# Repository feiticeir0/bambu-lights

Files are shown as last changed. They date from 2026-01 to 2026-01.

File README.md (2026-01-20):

# Bambu P1S – External LED Light (MQTT Controlled)

This project adds an external LED light strip to the Bambu Lab P1S printer, synchronized with the internal chamber light using MQTT over the local network.

The goal is to improve visibility inside the printer while keeping the behavior fully aligned with the printer’s native light control, without modifying firmware or adding manual switches.

---

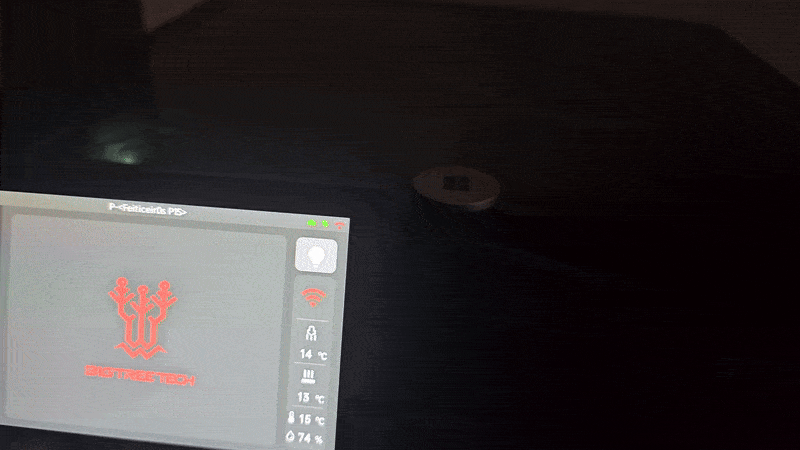
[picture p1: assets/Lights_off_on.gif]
Bambu Lights


## Introduction

The built-in light of the Bambu P1S is functional but relatively weak, especially for long prints, monitoring, or video recording.

You have two options to add a LED strip to the printer:

* Add a LED strip that consumes less than 0.3 amps and you can replace the connection to the onboard LED light and use the printer button to turn the light on and off
* Add a LED strip that consumes more than 0.3 amps, use an external power and not control the leds using the printer. 

Instead of using an always-on LED strip or a separate switch, and not being able to use the printer to turn the lights on and off, this project listens to the printer’s own MQTT messages and mirrors the state of the internal chamber light. 

When the chamber light turns on, the external LED strip turns on. When it turns off, the external light turns off as well, using smooth fade-in and fade-out transitions.

Everything runs locally.

## Why This Project

- Improve internal visibility of the printer
- Keep lighting behavior consistent with the printer
- No firmware modifications
- No cloud services
- No manual controls
- Fully reversible installation
- Smooth and non-intrusive light transitions

## How It Works

- An ESP32 connects to the same local network as the printer
- It subscribes to the MQTT topic published by the printer
- The printer reports its internal state, including the chamber light
- When the chamber light state changes:
  - ON → external LED fades in
  - OFF → external LED fades out
- A MOSFET switches the LED power safely

## Hardware Required

### Electronics
- ESP32 board (Seeed XIAO ESP32-S3 used in this project)
- IRLZ44N MOSFET
- 10k resistor
- 220 ohms resistor
- 5mm LED (color not important)
- 2x USB-A Pcb mount

### Power

- Powered via USB
- LED power is routed through the ESP32 5 V pin by design
- Common ground between ESP32 and LED strip

## 3D Printed Parts

A custom 3D printed enclosure is used to:

- Hold the PCB securely
- Protect the electronics
- Provide cable strain relief
- Mount the assembly on the back of the printer

[STL files are provided and can be printed without supports.](3D/README.md)

## Electrical Schematic and PCB

The schematic includes:

- ESP32 GPIO to MOSFET gate connection
- Gate pull-down resistor
- MOSFET low-side switching for the LED strip
- Shared ground reference
- Status LED output

The schematic files are included in the repository, in the [PCB directory.](Electrical/README.md)

### PCB
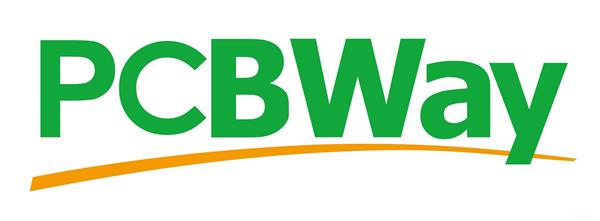
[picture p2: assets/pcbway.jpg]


A dedicated PCB was designed specifically for this project.

[You can get it directly from PCBWay.](https://www.pcbway.com/project/shareproject/Bambu_Lights_8b3fba62.html) 

**FYI:** I don't get anything from it, but they have sponsered it and I'm gratefull for it. 

The PCB is not necessary for the project - in [PCB](PCB/README.md) I have photos of the prototype and the schematics from Fritzing. 

## Code

The code runs on the Xiao ESP32-S3 and handles:

- WiFi connection (station mode)
- Secure MQTT connection to the printer (TLS)
- JSON parsing of printer status messages
- Detection of chamber light state changes
- PWM-based fade-in and fade-out animations
- Automatic reconnection to WiFi and MQTT

## Security

**TLS certificate validation is disabled, which is acceptable in a trusted local network environment.**

## Assembly
Here's pictures of everything assembled. [You can read more instructions on Electrical](Electrical/README.md)

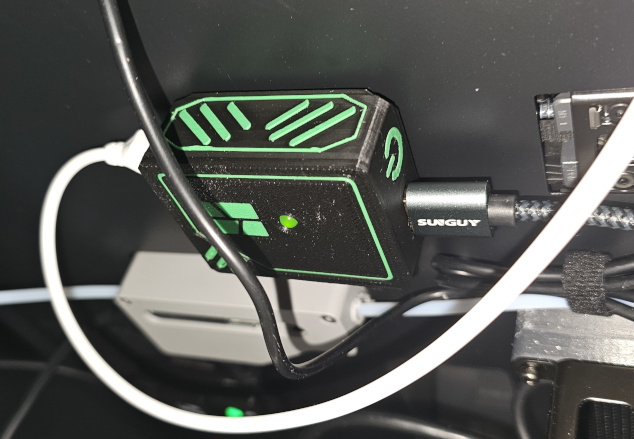
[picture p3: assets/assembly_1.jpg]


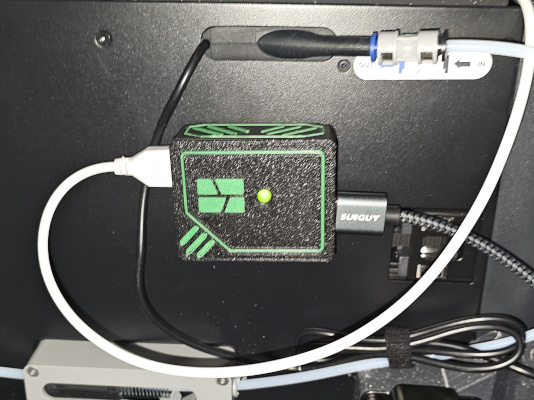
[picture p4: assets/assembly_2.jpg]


For power, I've connected it to [Biqu Panda Branch](https://biqu.equipment/products/biqu-power-supply-solutions?variant=42174177673314). 

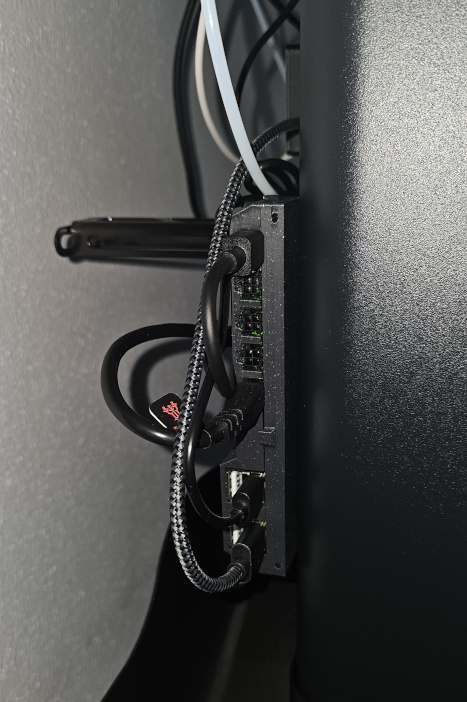
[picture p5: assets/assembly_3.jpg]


## TODO
- Verify if we are getting all the MQTT strings from the printer. Sometimes the lights don't turn on, because the string we're searching for does not appears. 

## License

This project is free software: you can redistribute it and/or modify
it under the terms of the GNU General Public License
as published by the Free Software Foundation, either version 3 of the License,
or (at your option) any later version.

This project is distributed in the hope that it will be useful,
but WITHOUT ANY WARRANTY; without even the implied warranty of
MERCHANTABILITY or FITNESS FOR A PARTICULAR PURPOSE. See the GNU General Public License for more details.

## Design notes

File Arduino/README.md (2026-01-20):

## Code

The code hasn't much in need of change, just some configurations.

First, you need to add your Wi-Fi details
```c
// WiFi
const char* WIFI_SSID     = "";    // Your wifi network
const char* WIFI_PASSWORD = "";    // your wifi network password
```

The next information needed is from your printer. 
* **PRINTER_IP** is the address of the printer on your network
* **ACCESS_CODE** you get it from the printer
* **PRINTER_SERIAL** is your printer serial number that you can also get from the menus of the printer. 

```c
// Bambu
const char* PRINTER_IP      = "xxx.xxx.xxx.xxx";  // Printer IP
const int   PRINTER_PORT    = 8883;    // No need to change - static
const char* PRINTER_USER    = "bblp";  // no change - static
const char* ACCESS_CODE     = "";      // LAN Access Code (From printer)
const char* PRINTER_SERIAL  = "";    // Serial number (From printer)
```

These are the libraries that you're going to need:
```c
#include <WiFi.h>
#include <WiFiClientSecure.h>
#include <PubSubClient.h>
#include <ArduinoJson.h>
```

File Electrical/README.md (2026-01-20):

## Electrical 

### Schematics
Here's the schematics for the "Bambu Lights" project:

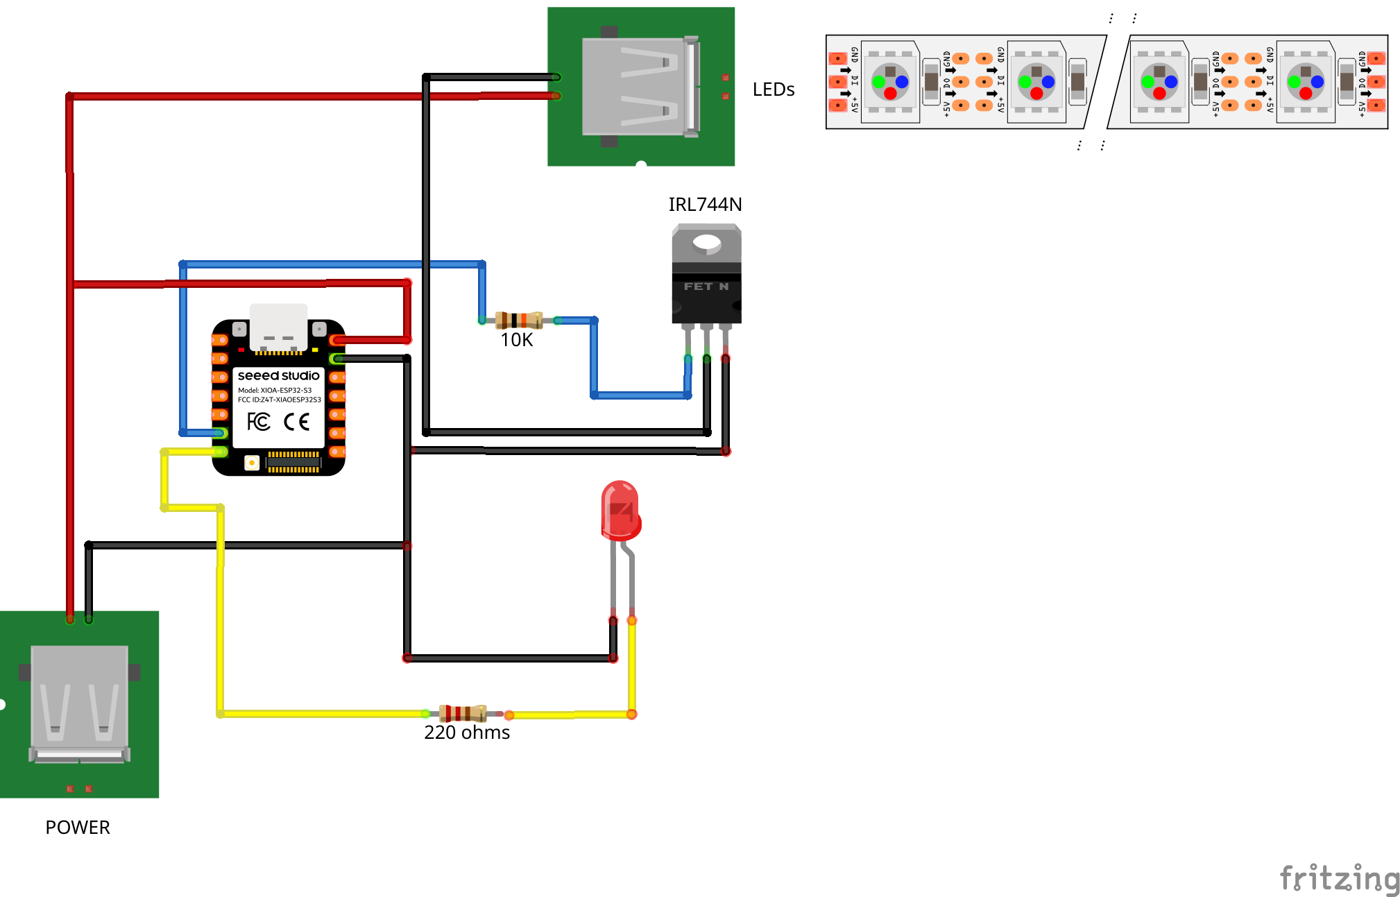
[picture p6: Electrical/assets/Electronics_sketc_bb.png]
schematics


You'll need:

* Seeed Studio Xiao ESP32-S3
* 10k resistor
* 220 ohms resistor
* 5mm led (color not important)
* 2x USB-A PCB mount
* IRL744N Mosffet

Following the schematics you'll end up with something like this (hope better):

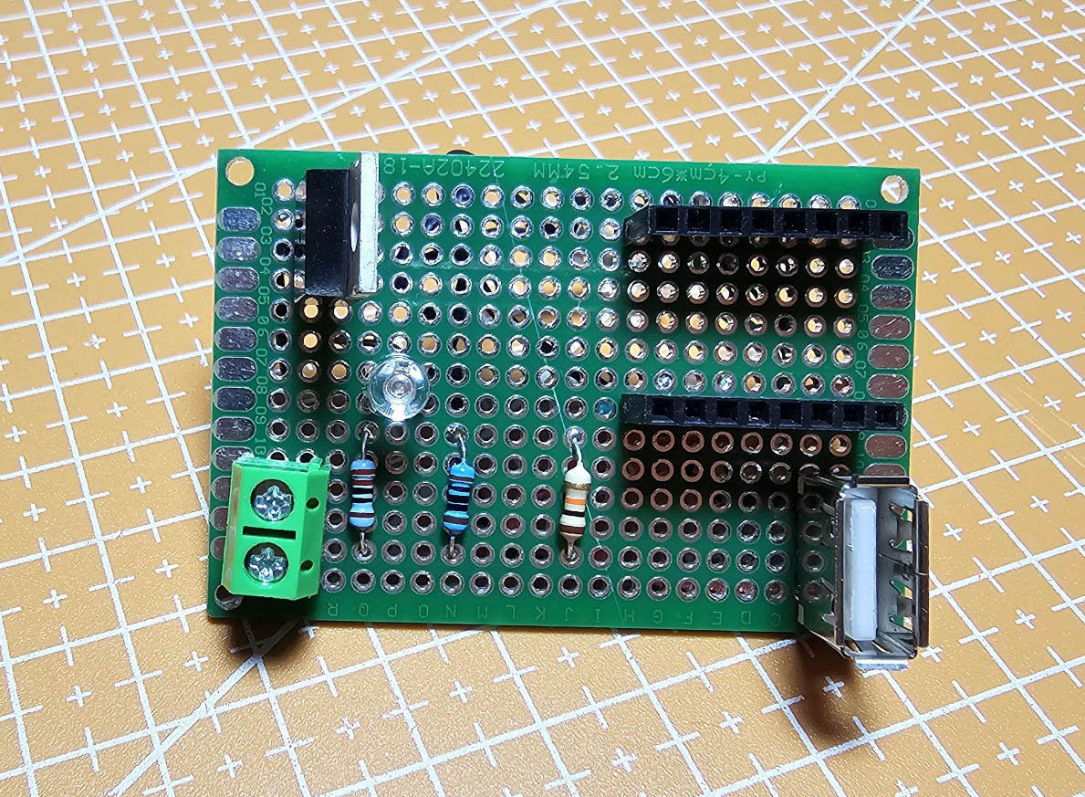
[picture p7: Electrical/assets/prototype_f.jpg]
prototype front


and the back

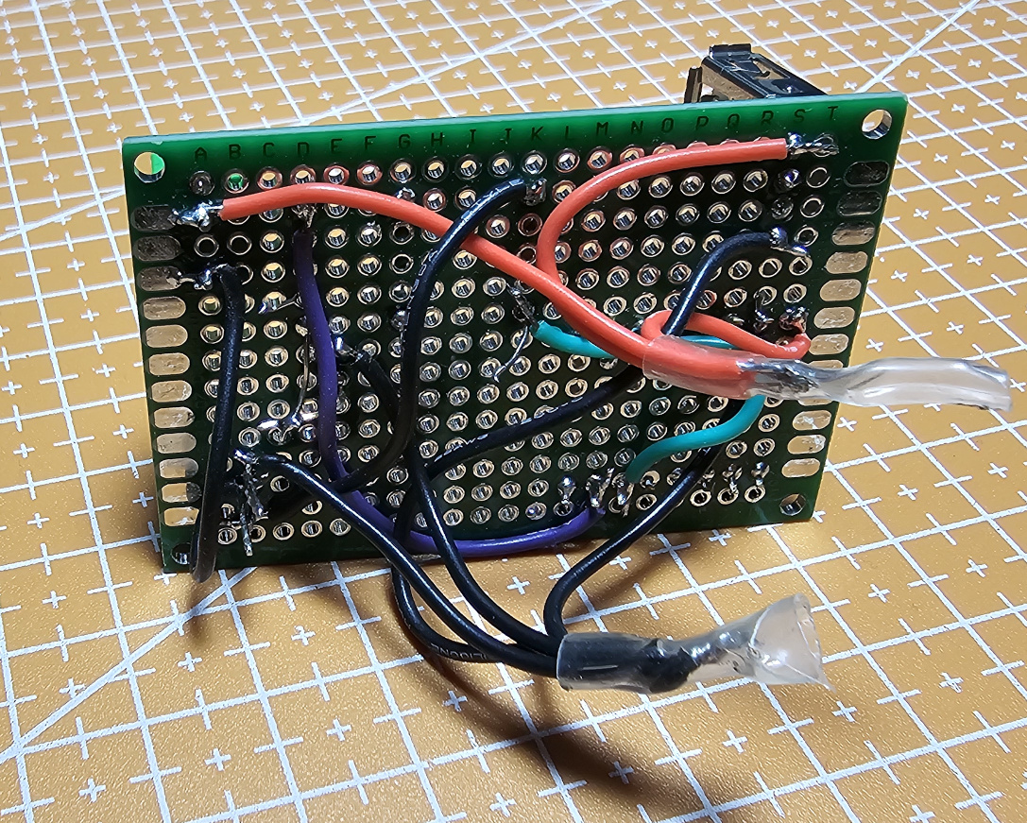
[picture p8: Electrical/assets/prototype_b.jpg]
prototype back


This is an older version.
It still has 3 resistors, a barrel jack to connect the LEDs and a straight USB-A PCB connector for the POWER. 

### PCB

Here's the PCB. 

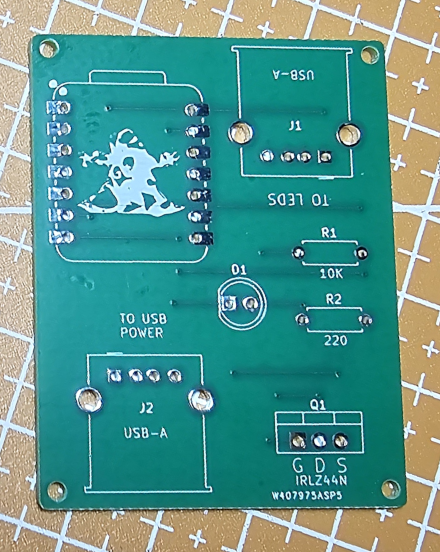
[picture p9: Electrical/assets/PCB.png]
PCB


[And here's the link to PCBWay if you want to make it.](https://www.pcbway.com/project/shareproject/Bambu_Lights_8b3fba62.html)

## Assembly

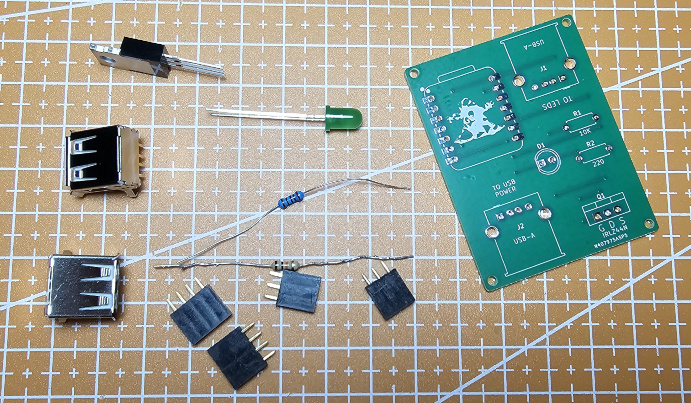
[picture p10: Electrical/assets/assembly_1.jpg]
Assembly parts


To assembly it you're going to need:

* PCB
* 2x USB-A PCB Mount
* headers for the Xiao ESP32-S3
* LED 5mm - color not important
* 220 ohms resistor
* 10k resistor
* IRLZ44N Mosffet

To assemble it, just place the pieces in the right places - it's not hard and all the holes are identified :smile: ! 

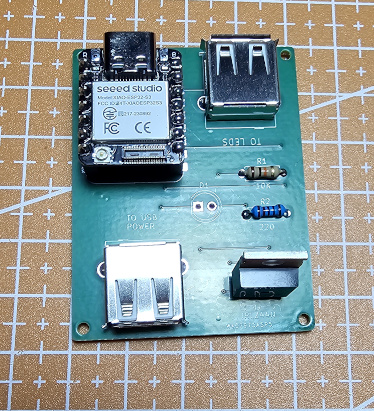
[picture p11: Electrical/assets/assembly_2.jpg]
Assembly parts


Before soldering the LED, measure the length of the legs so, when you place everything inside the 3D printed enclosure, the LED stays near the lid, almost touching it. 

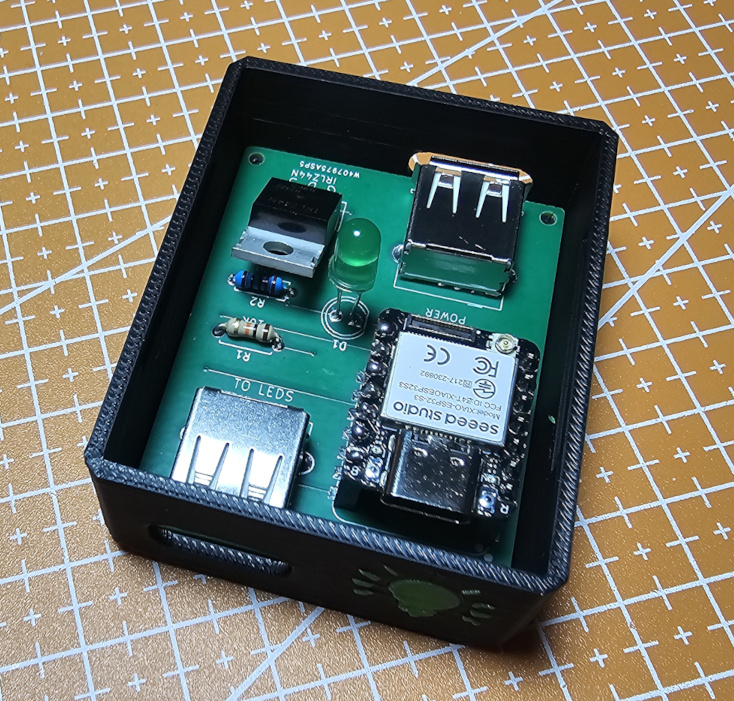
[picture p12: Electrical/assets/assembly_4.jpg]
Assembly parts


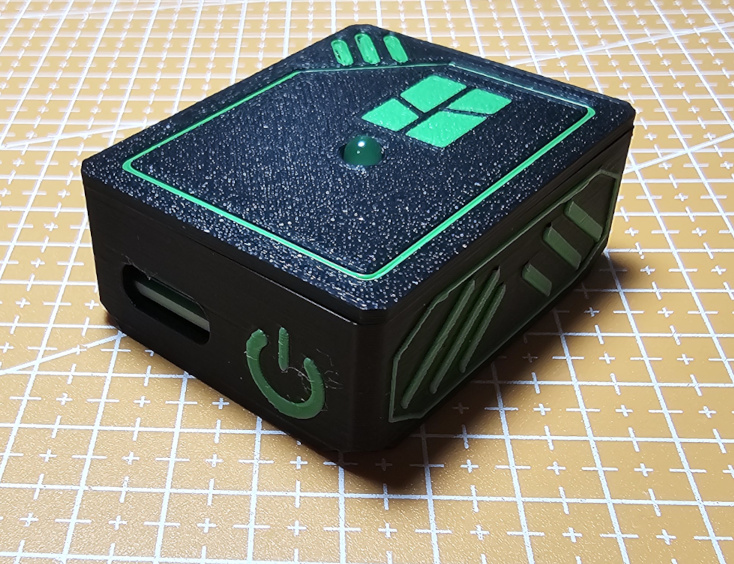
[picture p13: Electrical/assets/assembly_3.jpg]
Assembly parts


**NOTE:** When assembling the PCB into the 3D printed enclosure, check the labels near the USB-A PCB mounts. 

The one labeled **POWER** is to the side where is the *POWER Symbol* and the one labeled **To LEDS** is to the side where the *LED symbol* is. 

To secure it to the printer, use a magnetic strip glued to the enclosure.

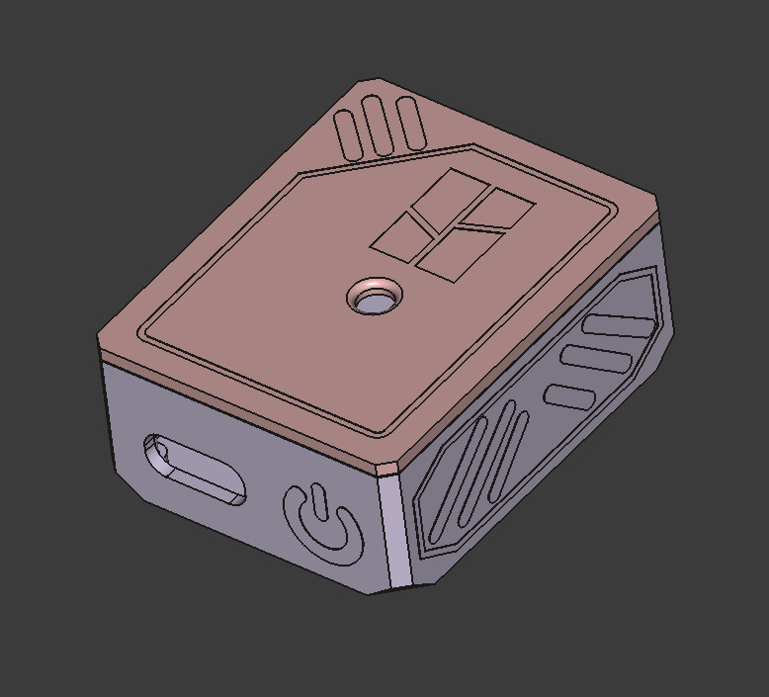
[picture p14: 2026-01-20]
3D/assets/3D_Rendering.jpg

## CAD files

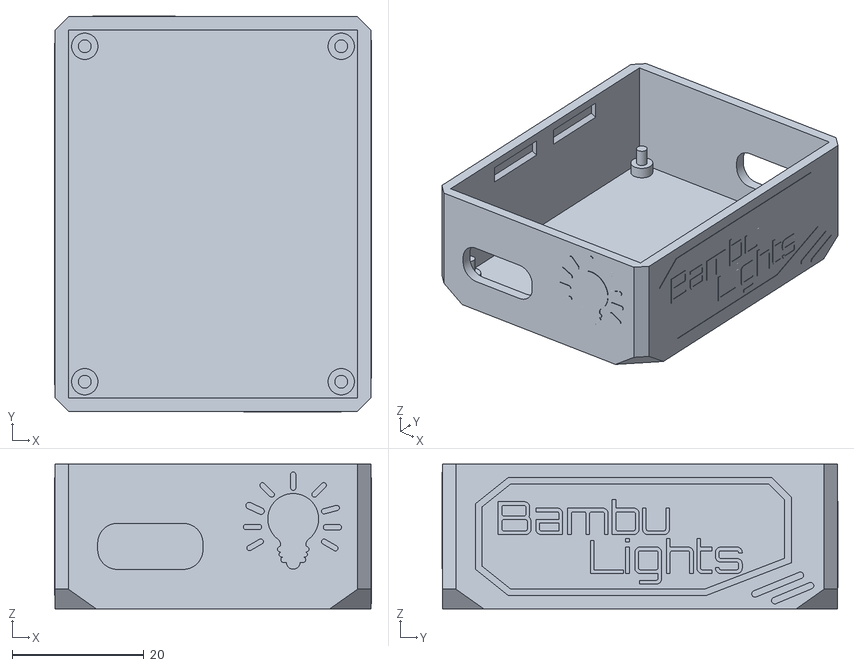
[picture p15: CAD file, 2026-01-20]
3D/assets/BambuLights-Body.stl
48.2 x 60.2 x 22.0

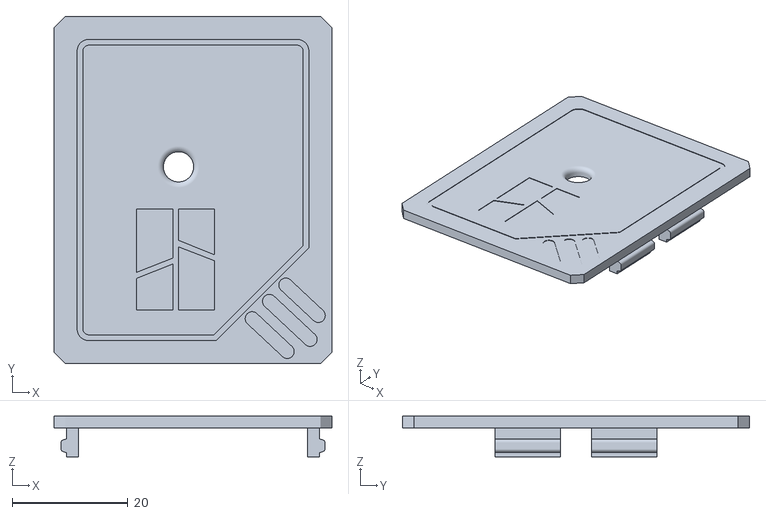
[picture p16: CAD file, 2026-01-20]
3D/assets/BambuLights-Lid.stl
48.0 x 60.0 x 7.00

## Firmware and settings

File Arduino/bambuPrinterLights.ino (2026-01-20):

#include <WiFi.h>
#include <WiFiClientSecure.h>
#include <PubSubClient.h>
#include <ArduinoJson.h>

/*
  =========================================================
   Projeto: Bambu P1S – Luz Externa Sincronizada por MQTT
   Hardware: ESP32 + MOSFET + fita LED
   Comunicação: MQTT over TLS (LAN)
  =========================================================
*/

// ==== CONFIGURAÇÃO ====

// Credenciais WiFi
const char* WIFI_SSID     = "";                // Your wifi network
const char* WIFI_PASSWORD = "";                // your wifi network password

// Dados da impressora Bambu
const char* PRINTER_IP      = ""; // Printer IP
const int   PRINTER_PORT    = 8883;           // MQTT PORT
const char* PRINTER_USER    = "bblp";         // no change - STATIC
const char* ACCESS_CODE     = "";             // LAN Access Code (From printer)
const char* PRINTER_SERIAL  = "";             // Serial number (From printer)

// Tópico MQTT onde a impressora publica o estado
String topicReport = String("device/") + PRINTER_SERIAL + "/report";

// Pino que controla o MOSFET (fita LED externa)
const int LED_CTRL_PIN = D5;

// Pino do LED de estado (status do sistema)
int STATUS_CTRL_PIN = D6;

// Ativar/desativar mensagens de debug
bool DEBUG = false;

// Guarda o último estado da luz para evitar ações repetidas
String lastLightMode = "";

// Clientes WiFi e MQTT
WiFiClientSecure espClient;
PubSubClient mqttClient(espClient);

// =========================================================
// CALLBACK MQTT
// É chamado sempre que chega uma mensagem MQTT
// =========================================================
void mqttCallback(char* topic, byte* payload, unsigned int length) {

  // Converter payload (bytes) numa String
  String jsonStr;
  jsonStr.reserve(length + 1);
  for (unsigned int i = 0; i < length; i++) {
    jsonStr += (char)payload[i];
  }

  // Debug opcional: mostra a mensagem MQTT completa
  if (DEBUG) {
    // Debug bruto
    Serial.println("=== MQTT message ===");
    Serial.print("Topic: ");
    Serial.println(topic);
    Serial.println(jsonStr);
  }

  // Documento JSON (tamanho grande para mensagens da Bambu)
  StaticJsonDocument<4096> doc;
  DeserializationError err = deserializeJson(doc, jsonStr);
  if (err) {
    Serial.print("Erro JSON: ");
    Serial.println(err.c_str());
    return;
  }

  // A informação relevante está dentro do objeto "print"
  JsonVariant print = doc["print"];
  if (print.isNull()) return;
  
  // Dentro de "print", existe o array "lights_report"
  JsonArray lights = print["lights_report"].as<JsonArray>();
  if (lights.isNull()) return;


  // Procurar especificamente o estado da "chamber_light"
  String chamberMode = "";
  for (JsonObject l : lights) {
    const char* node = l["node"];
    const char* mode = l["mode"];
    
    // Estamos interessados apenas na luz interna da câmara
    if (node && mode && String(node) == "chamber_light") {
      chamberMode = String(mode);
      break;
    }
  }

  if (chamberMode == "") return;

  // Só agir se o estado mudou (evita animações repetidas)
  if (chamberMode != lastLightMode) {
    lastLightMode = chamberMode;
    Serial.print("Luz interna (chamber_light): ");
    Serial.println(chamberMode);

    if (chamberMode == "on") {
      // Liga a fita LED externa com fade-in
      animateStripOn();       // fade in
      Serial.println(">> FITA: LIGADA");
    } else {
      // Desliga a fita LED externa com fade-out
      animateStripOff();     // fade out
      Serial.println(">> FITA: DESLIGADA");
    }
  }
}
// =========================================================
// FUNÇÃO DE LIGAÇÃO AO MQTT DA BAMBU
// =========================================================

void connectMQTT() {
  while (!mqttClient.connected()) {
    Serial.print("A ligar ao MQTT da Bambu... ");

    // Client ID único baseado no MAC do ESP32
    String clientId = "ESP32-Bambu-";
    clientId += String((uint32_t)ESP.getEfuseMac(), HEX);

    // Autenticação MQTT com user fixo + access code
    if (mqttClient.connect(clientId.c_str(), PRINTER_USER, ACCESS_CODE)) {
      Serial.println("Ligado!");
      mqttClient.subscribe(topicReport.c_str());
      Serial.print("Subscrito em: ");
      Serial.println(topicReport);
    } else {
      Serial.print("falhou, rc=");
      Serial.print(mqttClient.state());
      Serial.println(" ; nova tentativa em 5s");
      delay(5000);
    }
  }
}

// =========================================================
// ANIMAÇÕES DA FITA LED
// =========================================================

// Fade-in suave
void animateStripOn() {
  Serial.println("Animacao: ligar fita");
  for (int b = 0; b <= 255; b++) {
    analogWrite(LED_CTRL_PIN, b);  // PWM 0..255
    delay(5);                      // velocidade do fade
  }
}

// Fade-out suave
void animateStripOff() {
  Serial.println("Animacao: desligar fita");
  for (int b = 255; b >= 0; b--) {
    analogWrite(LED_CTRL_PIN, b);
    delay(5);
  }
}

// =========================================================
// SETUP
// =========================================================
void setup() {
  Serial.begin(115200);
  delay(1000);

  // Configuração dos pinos
  pinMode(LED_CTRL_PIN, OUTPUT);
  pinMode(STATUS_CTRL_PIN, OUTPUT);
  digitalWrite (STATUS_CTRL_PIN, LOW);
  analogWrite(LED_CTRL_PIN, 0);
  
  Serial.println();
  Serial.println("Bambu MQTT - Luz interna");

  // Ligação WiFi
  WiFi.mode(WIFI_STA);
  WiFi.disconnect(); // garante estado limpo
  WiFi.begin(WIFI_SSID, WIFI_PASSWORD);
  WiFi.setTxPower(WIFI_POWER_8_5dBm);

  Serial.print("A ligar ao WiFi");
  while (WiFi.status() != WL_CONNECTED) {
    // Pisca o LED de status enquanto liga
    digitalWrite (STATUS_CTRL_PIN, HIGH);
    delay(300);
    digitalWrite (STATUS_CTRL_PIN, LOW);
    delay(300);
    Serial.print(".");
  }

  Serial.println();
  digitalWrite (STATUS_CTRL_PIN, HIGH);
  Serial.print("WiFi ligado. IP: ");
  Serial.println(WiFi.localIP());

  // Esperar alguns segundos para deixar a impressora assentar e 
  // caso o LED esteja aceso, acender também 
  delay (10000);

  // TLS sem verificar certificado (simples em LAN)
  espClient.setInsecure();
  mqttClient.setServer(PRINTER_IP, PRINTER_PORT);
  mqttClient.setCallback(mqttCallback);
  
  connectMQTT();
}

// =========================================================
// LOOP PRINCIPAL
// =========================================================
void loop() {
  // Garante ligação MQTT ativa
  if (!mqttClient.connected()) {
    connectMQTT();
  }
  
  // Processa mensagens MQTT
  mqttClient.loop();
}
